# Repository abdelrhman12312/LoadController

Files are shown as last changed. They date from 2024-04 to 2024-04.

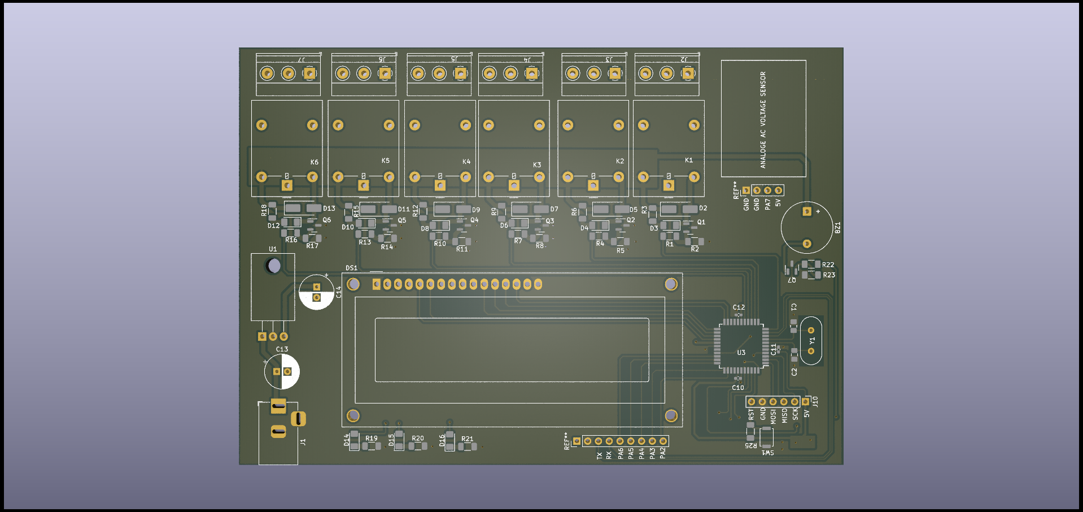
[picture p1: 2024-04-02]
MotorControlV1.0/MotorControlV1.03.png

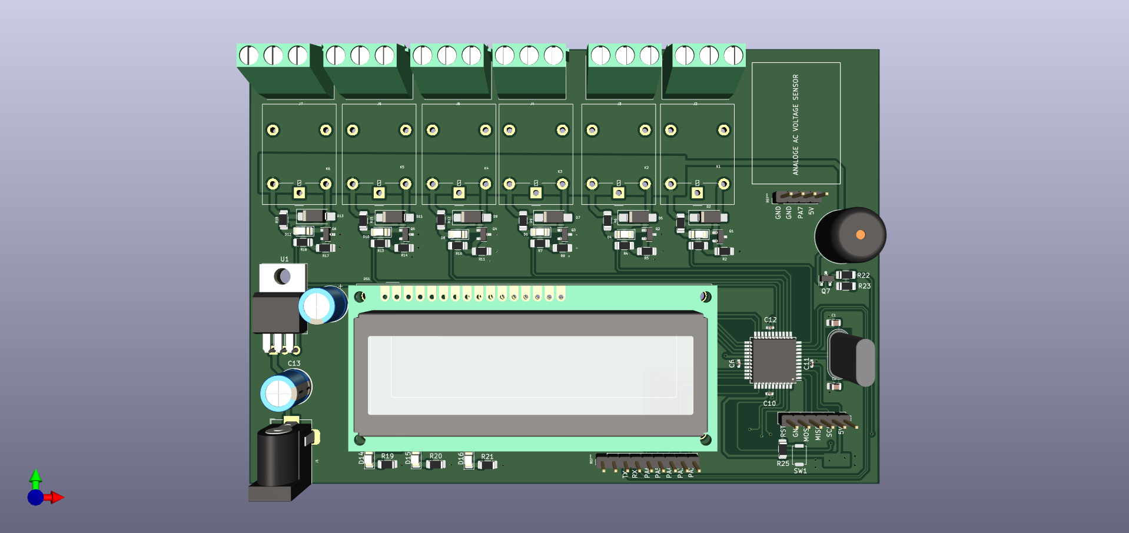
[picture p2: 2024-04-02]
MotorControlV1.0/MotorControlV1.00000.png

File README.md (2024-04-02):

# LoadController
you can view the circuit here :
https://kicanvas.org/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

MotorControlV1 0

MotorControlV1 03

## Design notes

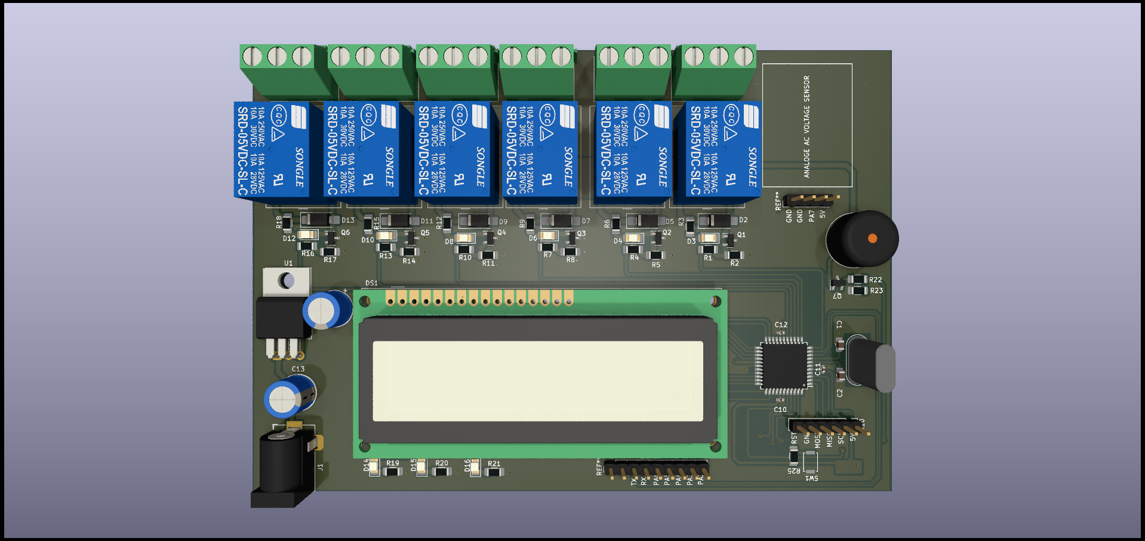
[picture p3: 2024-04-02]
MotorControlV1.0/MotorControlV1.0.png

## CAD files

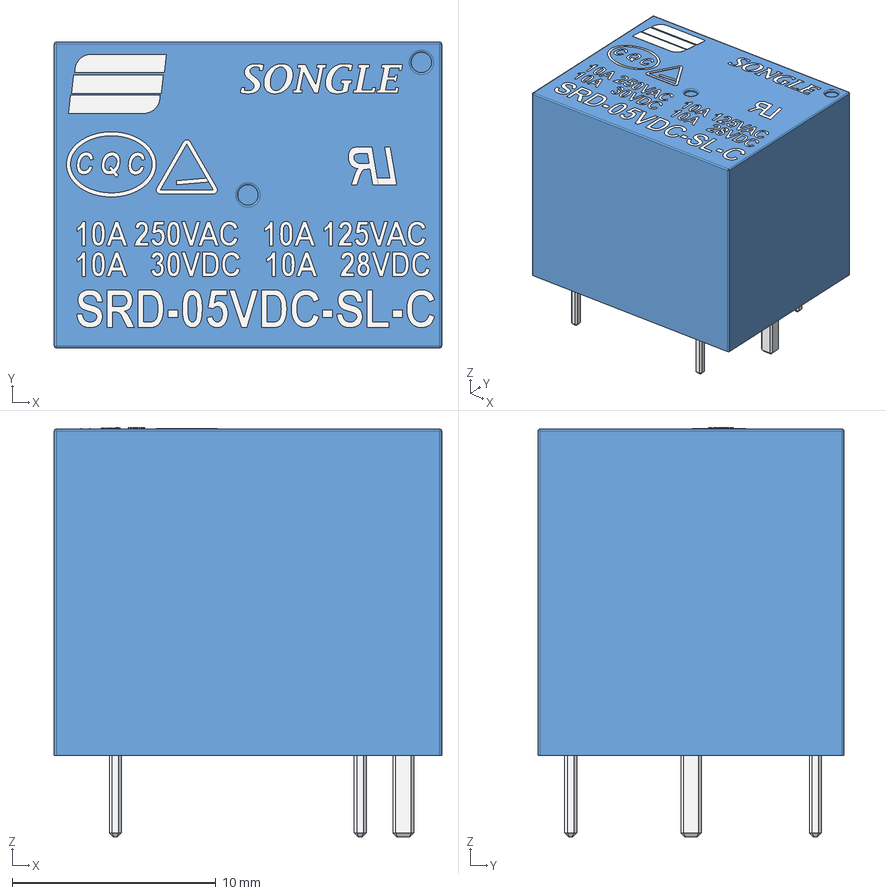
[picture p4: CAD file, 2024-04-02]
MotorControlV1.0/SRD-05VDC-SL-C(1)/SRD-05VDC-SL-C.step
19.0 x 15.0 x 20.1 mm

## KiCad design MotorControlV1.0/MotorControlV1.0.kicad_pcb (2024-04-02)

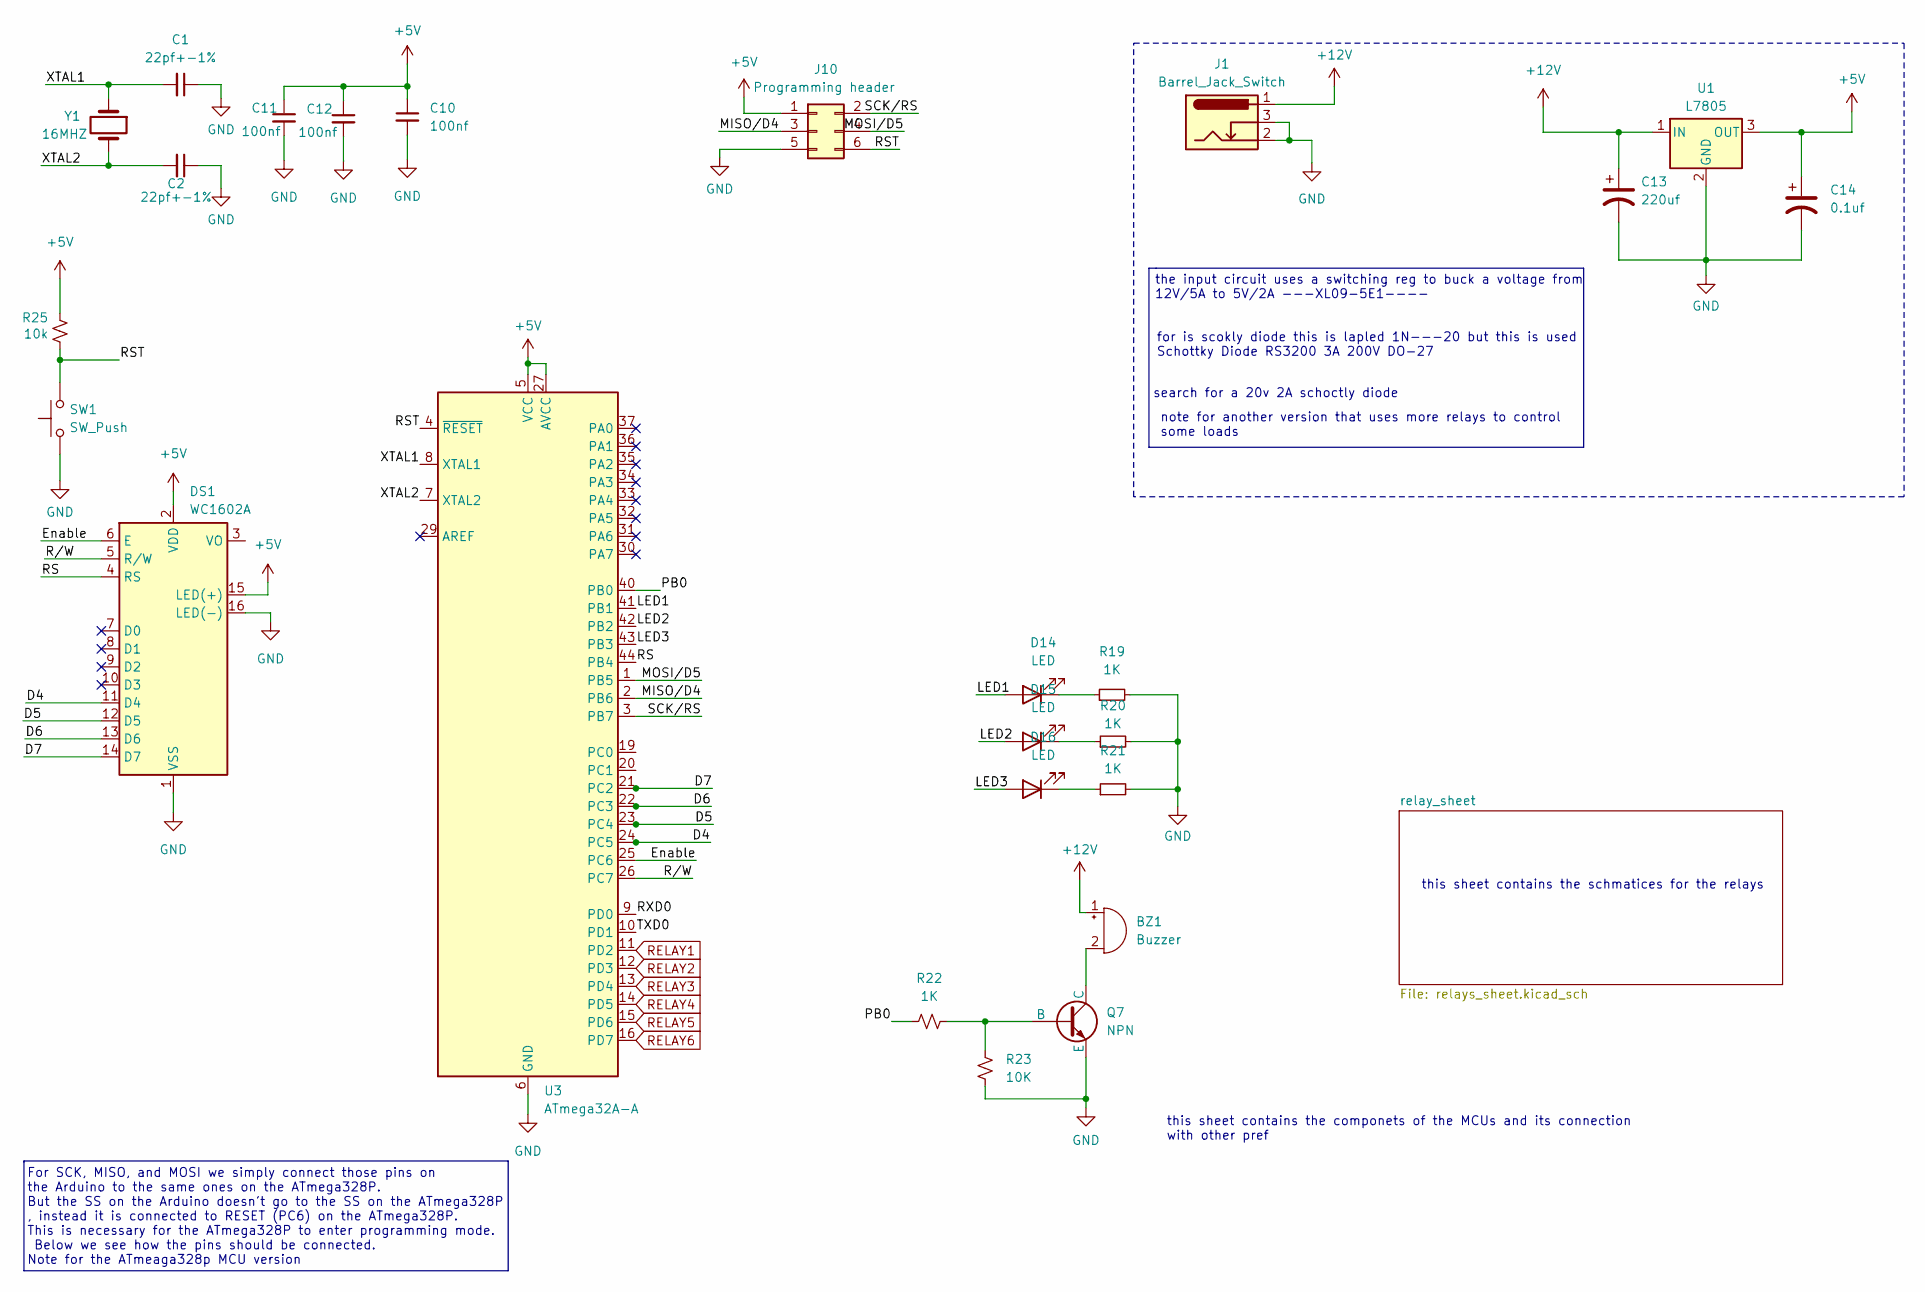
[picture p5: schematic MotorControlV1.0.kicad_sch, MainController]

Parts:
BZ1: Buzzer; Buzzer_12x9.5RM7.6
C1, C2: 22pf+-1%; C_0805_2012Metric_Pad1.18x1.45mm_HandSolder
C10, C11, C12: 100nf; C_0402_1005Metric_Pad0.74x0.62mm_HandSolder
C13: 220uf; CP_Radial_D8.0mm_P2.50mm
C14: 0.1uf; CP_Radial_D8.0mm_P2.50mm
D14, D15, D16: LED; LED_1206_3216Metric_Pad1.42x1.75mm_HandSolder
DS1: WC1602A
J1: Barrel_Jack_Switch; BarrelJack_Horizontal
J10: Programming header; PinHeader_1x06_P2.54mm_Vertical
Q7: NPN; SOT-23
R19, R20, R21, R22: 1K; R_1206_3216Metric_Pad1.30x1.75mm_HandSolder
R23: 10K; R_1206_3216Metric_Pad1.30x1.75mm_HandSolder
R25: 10k; R_1206_3216Metric_Pad1.30x1.75mm_HandSolder
SW1: SW_Push; SW_Push_SPST_NO_Alps_SKRK
U1: L7805; TO-220-3_Horizontal_TabDown
U3: ATmega32A-A; TQFP-44_10x10mm_P0.8mm
Y1: 16MHZ; Crystal_HC49-U_Vertical

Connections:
+5V: C10.1, C11.1, C12.1, C14.1, DS1.2 (VDD), DS1.15 (LED(+)), J10.1, R25.2, U1.3 (OUT), U3.5 (VCC), U3.17 (VCC), U3.27 (AVCC), U3.38 (VCC)
+12V: BZ1.1 (-), C13.1, J1.1, U1.1 (IN); also elsewhere on the board
/D4: DS1.11 (D4), U3.24 (PC5)
/D5: DS1.12 (D5), U3.23 (PC4)
/D6: DS1.13 (D6), U3.22 (PC3)
/D7: DS1.14 (D7), U3.21 (PC2)
/Enable: DS1.6 (E), U3.25 (PC6)
/LED1: D14.2 (A), U3.41 (PB1)
/LED2: D15.2 (A), U3.42 (PB2)
/LED3: D16.2 (A), U3.43 (PB3)
/MISO/D4: J10.3, U3.2 (PB6)
/MOSI/D5: J10.4, U3.1 (PB5)
/PB0: R22.1, U3.40 (PB0)
/RS: DS1.4 (RS), U3.44 (PB4)
/RST: J10.6, R25.1, SW1.2, U3.4 (~RESET)
/RXD0: U3.9 (PD0)
/R/W: DS1.5 (R/W), U3.26 (PC7)
/SCK/RS: J10.2, U3.3 (PB7)
/TXD0: U3.10 (PD1)
/XTAL1: C1.2, U3.8 (XTAL1), Y1.1
/XTAL2: C2.2, U3.7 (XTAL2), Y1.2
GND: C1.1, C2.1, C10.2, C11.2, C12.2, C13.2, C14.2, DS1.1 (VSS), DS1.16 (LED(-)), J1.2, J1.3, J10.5, Q7.3 (E), R19.2, R20.2, R21.2, R23.2, SW1.1, U1.2 (GND), U3.6 (GND), U3.18 (GND), U3.28 (GND), U3.39 (GND); also elsewhere on the board
unnamed: BZ1.2 (+), Q7.1 (C)
unnamed: D14.1 (K), R19.1
unnamed: D15.1 (K), R20.1
unnamed: D16.1 (K), R21.1
unnamed: Q7.2 (B), R22.2, R23.1
RELAY1: U3.11 (PD2); also elsewhere on the board
RELAY2: U3.12 (PD3); also elsewhere on the board
RELAY3: U3.13 (PD4); also elsewhere on the board
RELAY4: U3.14 (PD5); also elsewhere on the board
RELAY5: U3.15 (PD6); also elsewhere on the board
RELAY6: U3.16 (PD7); also elsewhere on the board

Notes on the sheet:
this sheet contains the schmatices for the relays
For SCK, MISO, and MOSI we simply connect those pins on the Arduino to the same ones on the ATmega328P. But the SS on the Arduino doesn't go to the SS on the ATmega328P , instead it is connected to RESET (PC6) on the ATmega328P. This is necessary for the ATmega328P to enter programming mode. Below 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
note for another version that uses more relays to control some loads
for is scokly diode this is lapled 1N---20 but this is used Schottky Diode RS3200 3A 200V DO-27
the input circuit uses a switching reg to buck a voltage from 12V/5A to 5V/2A ---XL09-5E1----
search for a 20v 2A schoctly diode
this sheet contains the componets of the MCUs and its connection with other pref

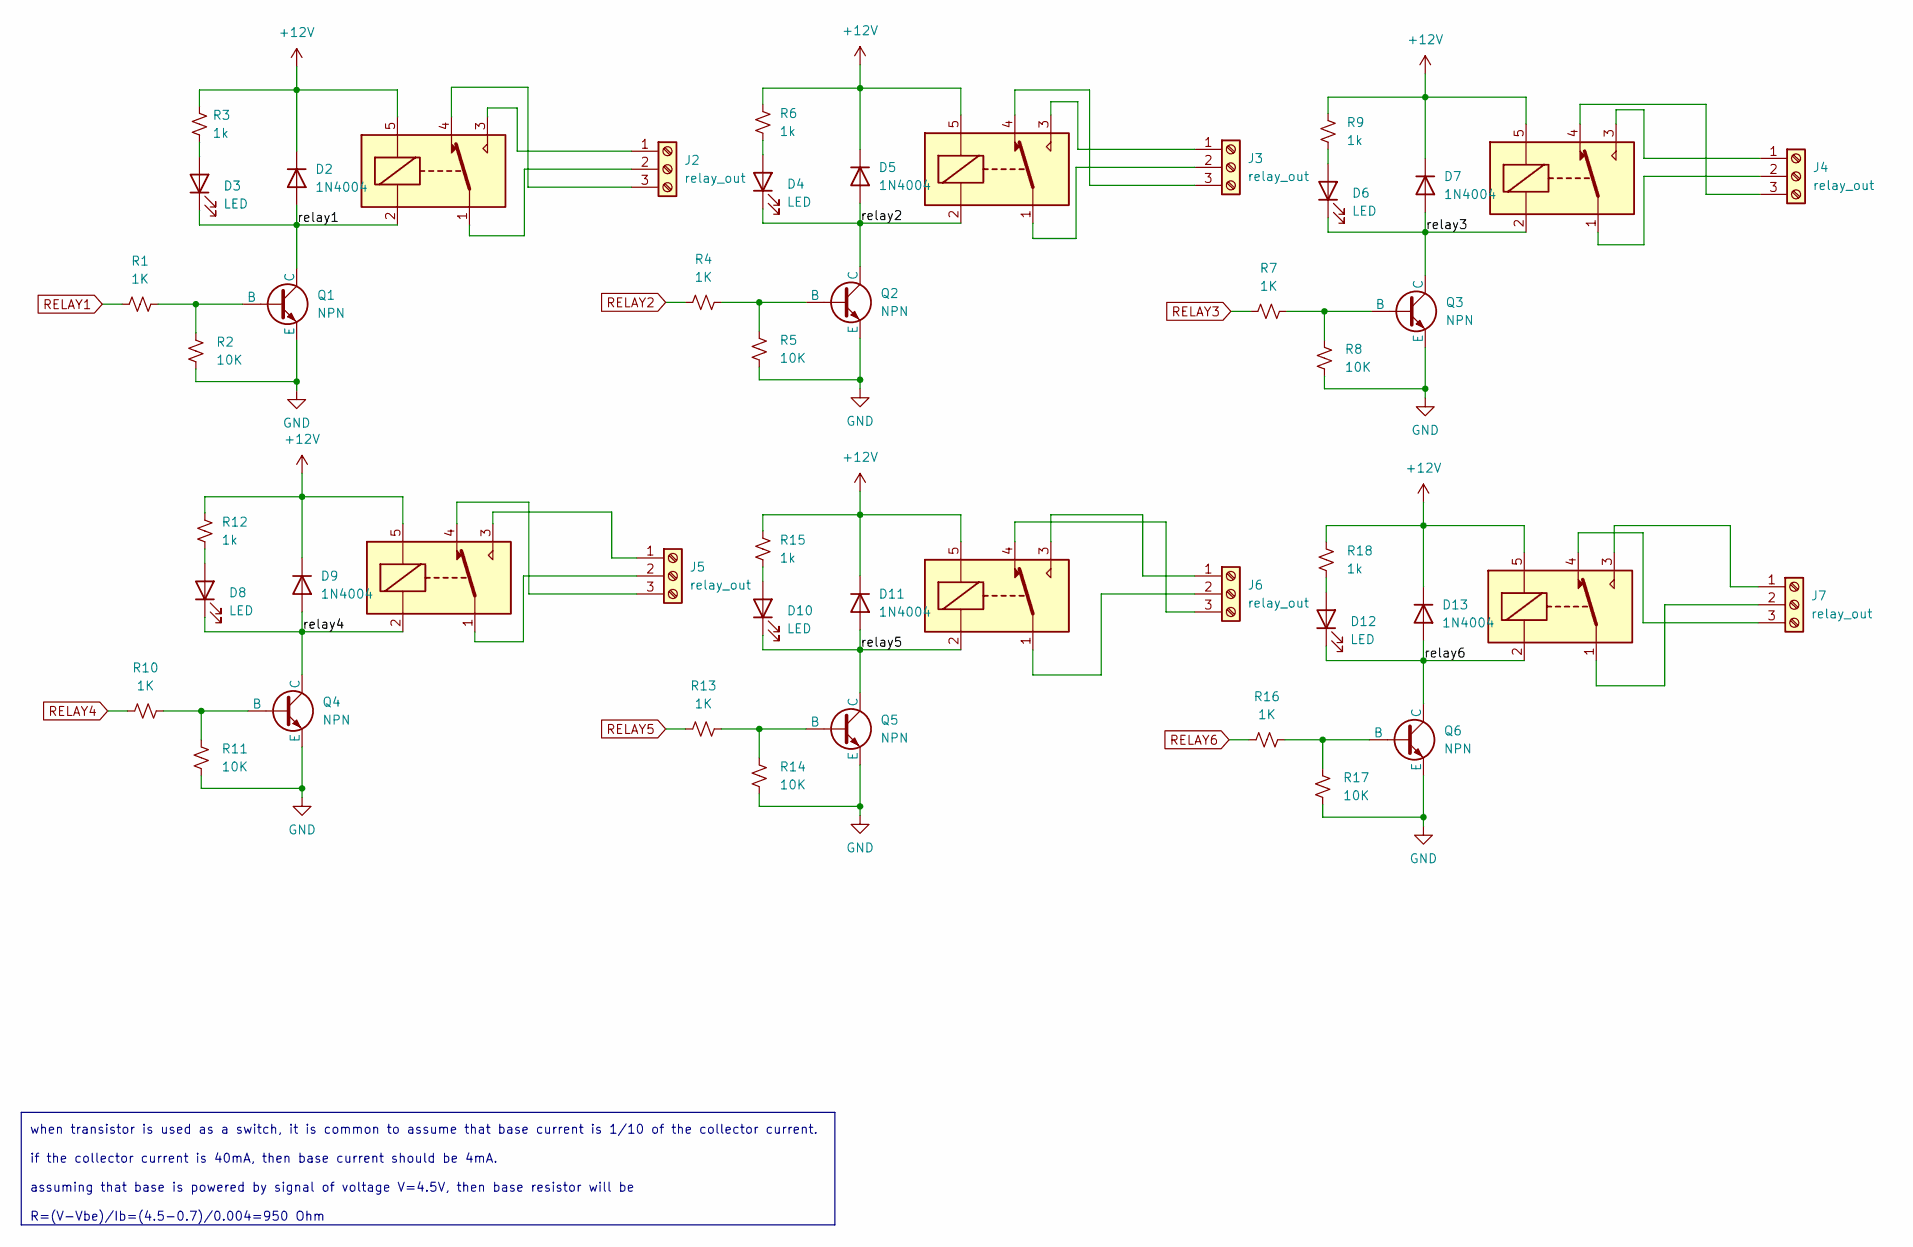
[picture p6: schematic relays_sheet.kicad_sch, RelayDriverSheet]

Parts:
D2, D5, D7, D9, D11, D13: 1N4004; D_SMA_Handsoldering
D3, D4, D6, D8, D10, D12: LED; LED_1206_3216Metric_Pad1.42x1.75mm_HandSolder
J2, J3, J4, J5, J6, J7: relay_out; TerminalBlock_Phoenix_MKDS-1,5-3_1x03_P5.00mm_Horizontal
K1, K2, K3, K4, K5, K6: G5LE-1; Relay_SPDT_Omron-G5LE-1
Q1, Q2, Q3, Q4, Q5, Q6: NPN; SOT-23
R1, R4, R7, R10, R13, R16: 1K; R_1206_3216Metric_Pad1.30x1.75mm_HandSolder
R2, R5, R8, R11, R14, R17: 10K; R_1206_3216Metric_Pad1.30x1.75mm_HandSolder
R3, R6, R9, R12, R15, R18: 1k; R_1206_3216Metric_Pad1.30x1.75mm_HandSolder

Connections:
+12V: D2.1 (K), D5.1 (K), D7.1 (K), D9.1 (K), D11.1 (K), D13.1 (K), K1.5, K2.5, K3.5, K4.5, K5.5, K6.5, R3.1, R6.1, R9.1, R12.1, R15.1, R18.1; also elsewhere on the board
/relay_sheet/relay1: D2.2 (A), D3.1 (K), K1.2, Q1.1 (C)
/relay_sheet/relay2: D4.1 (K), D5.2 (A), K2.2, Q2.1 (C)
/relay_sheet/relay3: D6.1 (K), D7.2 (A), K3.2, Q3.1 (C)
/relay_sheet/relay4: D8.1 (K), D9.2 (A), K4.2, Q4.1 (C)
/relay_sheet/relay5: D10.1 (K), D11.2 (A), K5.2, Q5.1 (C)
/relay_sheet/relay6: D12.1 (K), D13.2 (A), K6.2, Q6.1 (C)
GND: Q1.3 (E), Q2.3 (E), Q3.3 (E), Q4.3 (E), Q5.3 (E), Q6.3 (E), R2.2, R5.2, R8.2, R11.2, R14.2, R17.2; also elsewhere on the board
unnamed: D3.2 (A), R3.2
unnamed: D4.2 (A), R6.2
unnamed: D6.2 (A), R9.2
unnamed: D8.2 (A), R12.2
unnamed: D10.2 (A), R15.2
unnamed: D12.2 (A), R18.2
unnamed: J2.1, K1.3
unnamed: J2.2, K1.1
unnamed: J2.3, K1.4
unnamed: J3.1, K2.3
unnamed: J3.2, K2.1
unnamed: J3.3, K2.4
unnamed: J4.1, K3.3
unnamed: J4.2, K3.1
unnamed: J4.3, K3.4
unnamed: J5.1, K4.3
unnamed: J5.2, K4.1
unnamed: J5.3, K4.4
unnamed: J6.1, K5.3
unnamed: J6.2, K5.1
unnamed: J6.3, K5.4
unnamed: J7.1, K6.3
unnamed: J7.2, K6.1
unnamed: J7.3, K6.4
unnamed: Q1.2 (B), R1.2, R2.1
unnamed: Q2.2 (B), R4.2, R5.1
unnamed: Q3.2 (B), R7.2, R8.1
unnamed: Q4.2 (B), R10.2, R11.1
unnamed: Q5.2 (B), R13.2, R14.1
unnamed: Q6.2 (B), R16.2, R17.1
RELAY1: R1.1; also elsewhere on the board
RELAY2: R4.1; also elsewhere on the board
RELAY3: R7.1; also elsewhere on the board
RELAY4: R10.1; also elsewhere on the board
RELAY5: R13.1; also elsewhere on the board
RELAY6: R16.1; also elsewhere on the board

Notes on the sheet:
when transistor is used as a switch, it is common to assume that base current is 1/10 of the collector current. if the collector current is 40mA, then base current should be 4mA. assuming that base is powered by signal of voltage V=4.5V, then base resistor will be R=(V-Vbe)/Ib=(4.5-0.7)/0.004=950 O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

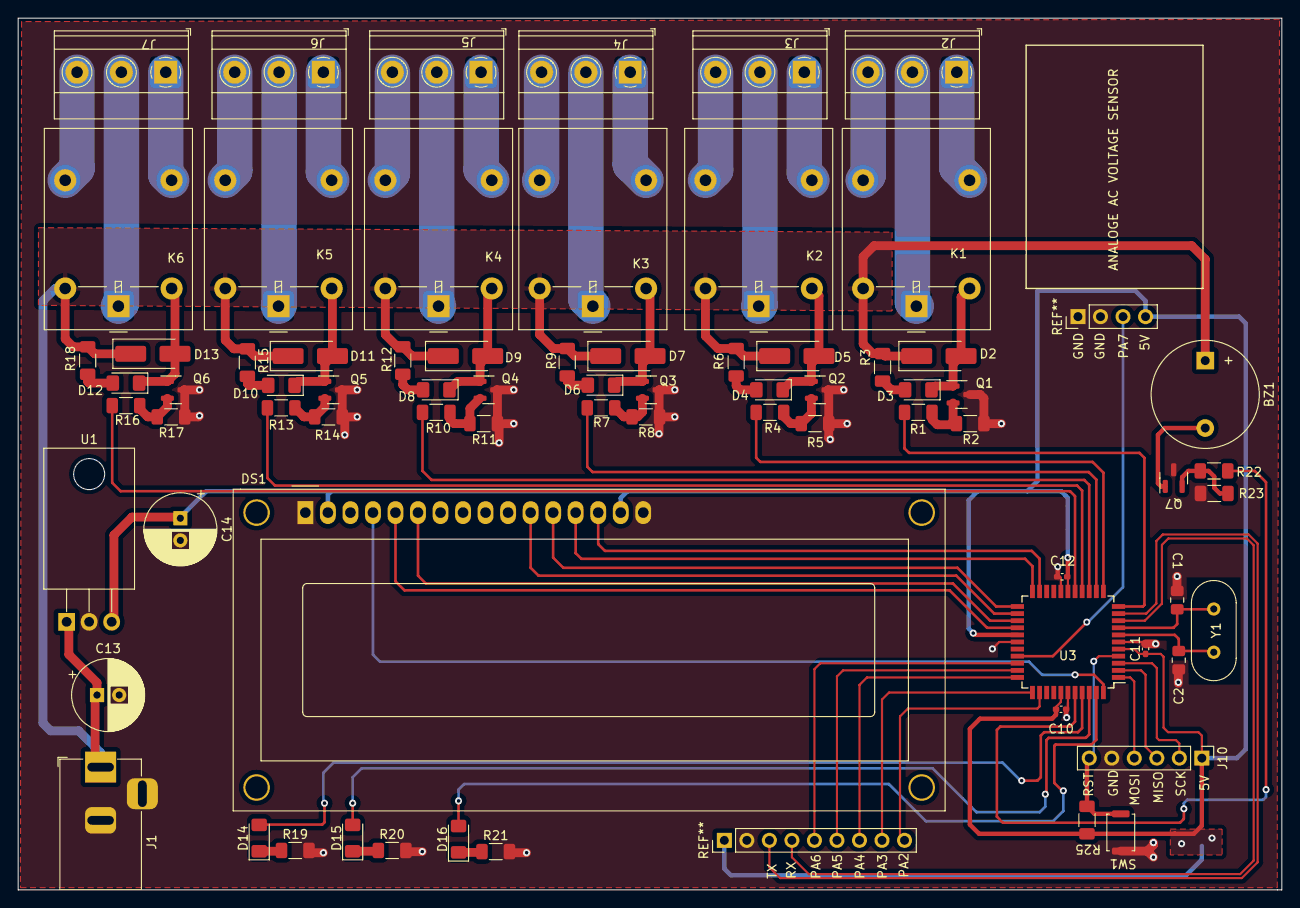
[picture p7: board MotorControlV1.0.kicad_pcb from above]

Board: 2 copper layers, 142.5 x 98.3 mm, 73 parts (0 on the bottom side), 67 nets.
